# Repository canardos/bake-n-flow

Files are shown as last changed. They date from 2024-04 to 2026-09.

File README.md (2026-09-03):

# Bake-n-Flow

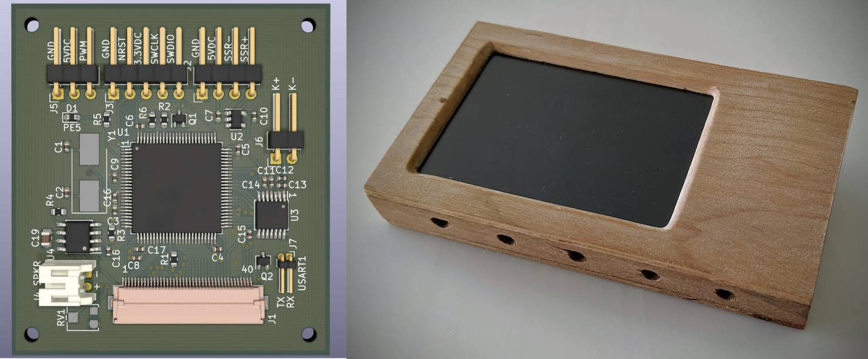
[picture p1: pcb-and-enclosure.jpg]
Reflow toaster oven controller


## Yet another (STM32F1-based) toaster reflow oven controller - PCB design and firmware

> [!Warning]
> This is personal project. It was built and works without issue for my purposes. It is made public here in case some part of it is useful to others, but **neither the hardware nor firmware have been rigorously tested**.

**Features:**

- Customizable profiles
- Reflow / baking operations
- Manual override controls
- Touch screen control

**This repo contains the firmware and PCB design.**

**See [custom electronics projects at duk.io](https://www.duk.io/blog/electronics-projects/) for full project details.**

https://github.com/canardos/bake-n-flow/assets/14832310/401d4c1e-f360-4829-90d8-4b5ea61bf341

## Build

The project uses the [PlatformIO](https://platformio.org/) dependency management/build system. If you have PlatformIO installed, executing the `run` command in the root folder *should* 🙏 be all that is required for a successful build. The `platformio.ini` file contains the required configuration and PlatformIO will download the required platform dependencies and toolchain.

**1. Clone repo and download submodules**

```shell
> git clone https://github.com/canardos/bake-n-flow.git
> cd bake-n-flow
> git submodule update --init
```

**2. Build firmware (PlatformIO must be installed)**

```shell
> pio run

Processing release (platform: ststm32; board: genericSTM32F103VD; framework: cmsis)
-----------------------------------------------------------------------------------
Verbose mode can be enabled via `-v, --verbose` option
CONFIGURATION: https://docs.platformio.org/page/boards/ststm32/genericSTM32F103VD.html
PLATFORM: ST STM32 (19.7.0) > STM32F103VD (64k RAM. 384k Flash)
HARDWARE: STM32F103VDT6 72MHz, 64KB RAM, 384KB Flash
DEBUG: Current (stlink) External (blackmagic, cmsis-dap, jlink, stlink)
PACKAGES: 
 - framework-cmsis @ 2.50501.200527 (5.5.1) 
 - framework-cmsis-stm32f1 @ 4.3.5 
 - tool-ldscripts-ststm32 @ 0.2.0 
 - toolchain-gccarmnoneeabi @ 1.120301.0 (12.3.1)
LDF: Library Dependency Finder -> https://bit.ly/configure-pio-ldf
LDF Modes: Finder ~ chain, Compatibility ~ soft
Found 4 compatible libraries
Scanning dependencies...
Dependency Graph
|-- libpekin @ 0.2.1
|-- libpekin_stm32
Building in release mode
Compiling piobuild/build/release/FrameworkCMSIS/gcc/startup_stm32f103xe.o
...
...
...
Archiving piobuild/build/release/lib7bf/libpekin_stm32.a
Indexing piobuild/build/release/lib7bf/libpekin_stm32.a
Archiving piobuild/build/release/lib72d/libpekin.a
Indexing piobuild/build/release/lib72d/libpekin.a
Linking piobuild/build/release/firmware.elf
Checking size piobuild/build/release/firmware.elf
Advanced Memory Usage is available via "PlatformIO Home > Project Inspect"
RAM:   [========= ]  95.0% (used 62248 bytes from 65536 bytes)
Flash: [=====     ]  50.5% (used 198660 bytes from 393216 bytes)
============================= [SUCCESS]
```

**3. Upload to device**

Similarly, use `pio run --target upload` to upload the firmware to the device. You'll likely need to update the upload settings in `platformio.ini` to reflect your settings, or use your own upload tool.

```shell
> pio run --target upload

Configuring upload protocol...
AVAILABLE: blackmagic, dfu, jlink, serial, stlink
CURRENT: upload_protocol = stlink
Uploading piobuild/build/release/firmware.elf
xPack OpenOCD, x86_64 Open On-Chip Debugger 0.10.0+dev-00378-ge5be992df (2020-06-26-09:27)
Licensed under GNU GPL v2
For bug reports, read
        http://openocd.org/doc/doxygen/bugs.html
debug_level: 1

hla_swd
target halted due to debug-request, current mode: Thread
xPSR: 0x01000000 pc: 0x0800108c msp: 0x20010000
** Programming Started **
** Programming Finished **
** Verify Started **
** Verified OK **
** Resetting Target **
shutdown command invoked
======================== [SUCCESS] Took 12.58 seconds =================================
```

**4. [optional] Create project files for IDE**

If you want to view/edit the project in your favorite IDE, use PlatformIO to generate the appropriate setup/workspace files and then import the project in the IDE:

```shell
> pio project init --ide [atom|clion|codeblocks|eclipse|emacs|netbeans|qtcreator|sublimetext|vim|visualstudio|vscode]
```

See the [PlatformIO documentation](https://docs.platformio.org) for further details.

### Using an alternate build system

**Platform dependencies**

If you wish to use a different build system, you will need:

| | |
|-|-|
| ST STM32 CMSIS headers | Peripheral/register definitions |
| CMSIS headers/source | CMSIS HAL functionality - SysTick_Config, NVIC_xxx etc.|
| CMSIS Cortex-M3 system source | `SystemInit()`/`SystemCoreClockUpdate()` implementation and `SystemCoreClock`|
| Startup source file | ASM file containing the startup code and vector table |
| Linker script | Tells the linker how to setup everything in flash/SRAM |

All of these are available in the [STM32 SDK](https://www.st.com/en/development-tools/stm32-software-development-tools.html) available from ST Micro.

**Compiling / linking**

`platformio.ini` lists the required compiler flags. Be sure to use `--specs=nano.specs` and `--specs=nosys.specs` when linking using your own tools, as the standard lib is be too large and is not used.

### Compiler

The project was compiled and tested with ~~`gcc-arm-none-eabi 9.2.1`~~ `gcc-arm-none-eabi 12.3.1`. It should work with any later GCC version and possibly with other compilers. The code contains some GCC flags and some C99 VLAs.

### Target requirements

| | |
|-|-|
|MCU  | STM32F103 with FSMC |
|Flash| >195kb |
|SRAM | >61kb |

It may be possible to get by with less SRAM by using a smaller drawing buffer (currently 40 lines - 38.4 kb)

## Dependencies

**CMSIS**

PlatformIO should automatically include/link the correct headers/sources from the STM32 SDK.

**LVGL**

[LVGL](https://github.com/lvgl/lvgl) v5.3 (git commit `9f216a55be65ec05c477ac55f73a6efad50f7680`) is used. It is included ~~as a Git submodule~~ in the`src/lvgl` folder.

**Libpekin**

[Libpekin](https://github.com/canardos/libpekin) is a collection of shared MCU-related code resulting from this and other projects. It's included as a Git submodule in the `lib` folder. PlatformIO will include the `lib` subfolders automatically.

## Hardware - PCB

The PCB was designed with KiCad v.5, but the files have been upgraded to v.7 and are located in `/hardware/pcb`. Gerber output for the first and only revision is located in `/hardware/pcb/plots`.

See the [KiCad documentation](https://docs.kicad.org/) for information on installing and using KiCad.

## Folder structure

```
BakeNFlow
|
+--hardware          | KiCad schematic and board design files
|
+--lib
|  |
|  +--libpekin       | Libpekin platform independent code
|  +--libpekin_stm32 | Libpekin STM32 specific code
|
+--src
|  |
|  +--audio_samples  | Audio sample data
|  +--devices        | Hardware device drivers
|  +--lvgl           | LVGL project
|  +--lvgl_driver    | Display/touch driver for LVGL
|  +--oven           | Oven hardware interface and state management
|  +--reflow         | Reflow data structures and state management
|  +--hal            | (exception handlers etc.)
|  +--ui             | UI code for LVGL
|
|--test              | No tests in use
```

## License

This software is available under the [MIT license](https://opensource.org/license/MIT).

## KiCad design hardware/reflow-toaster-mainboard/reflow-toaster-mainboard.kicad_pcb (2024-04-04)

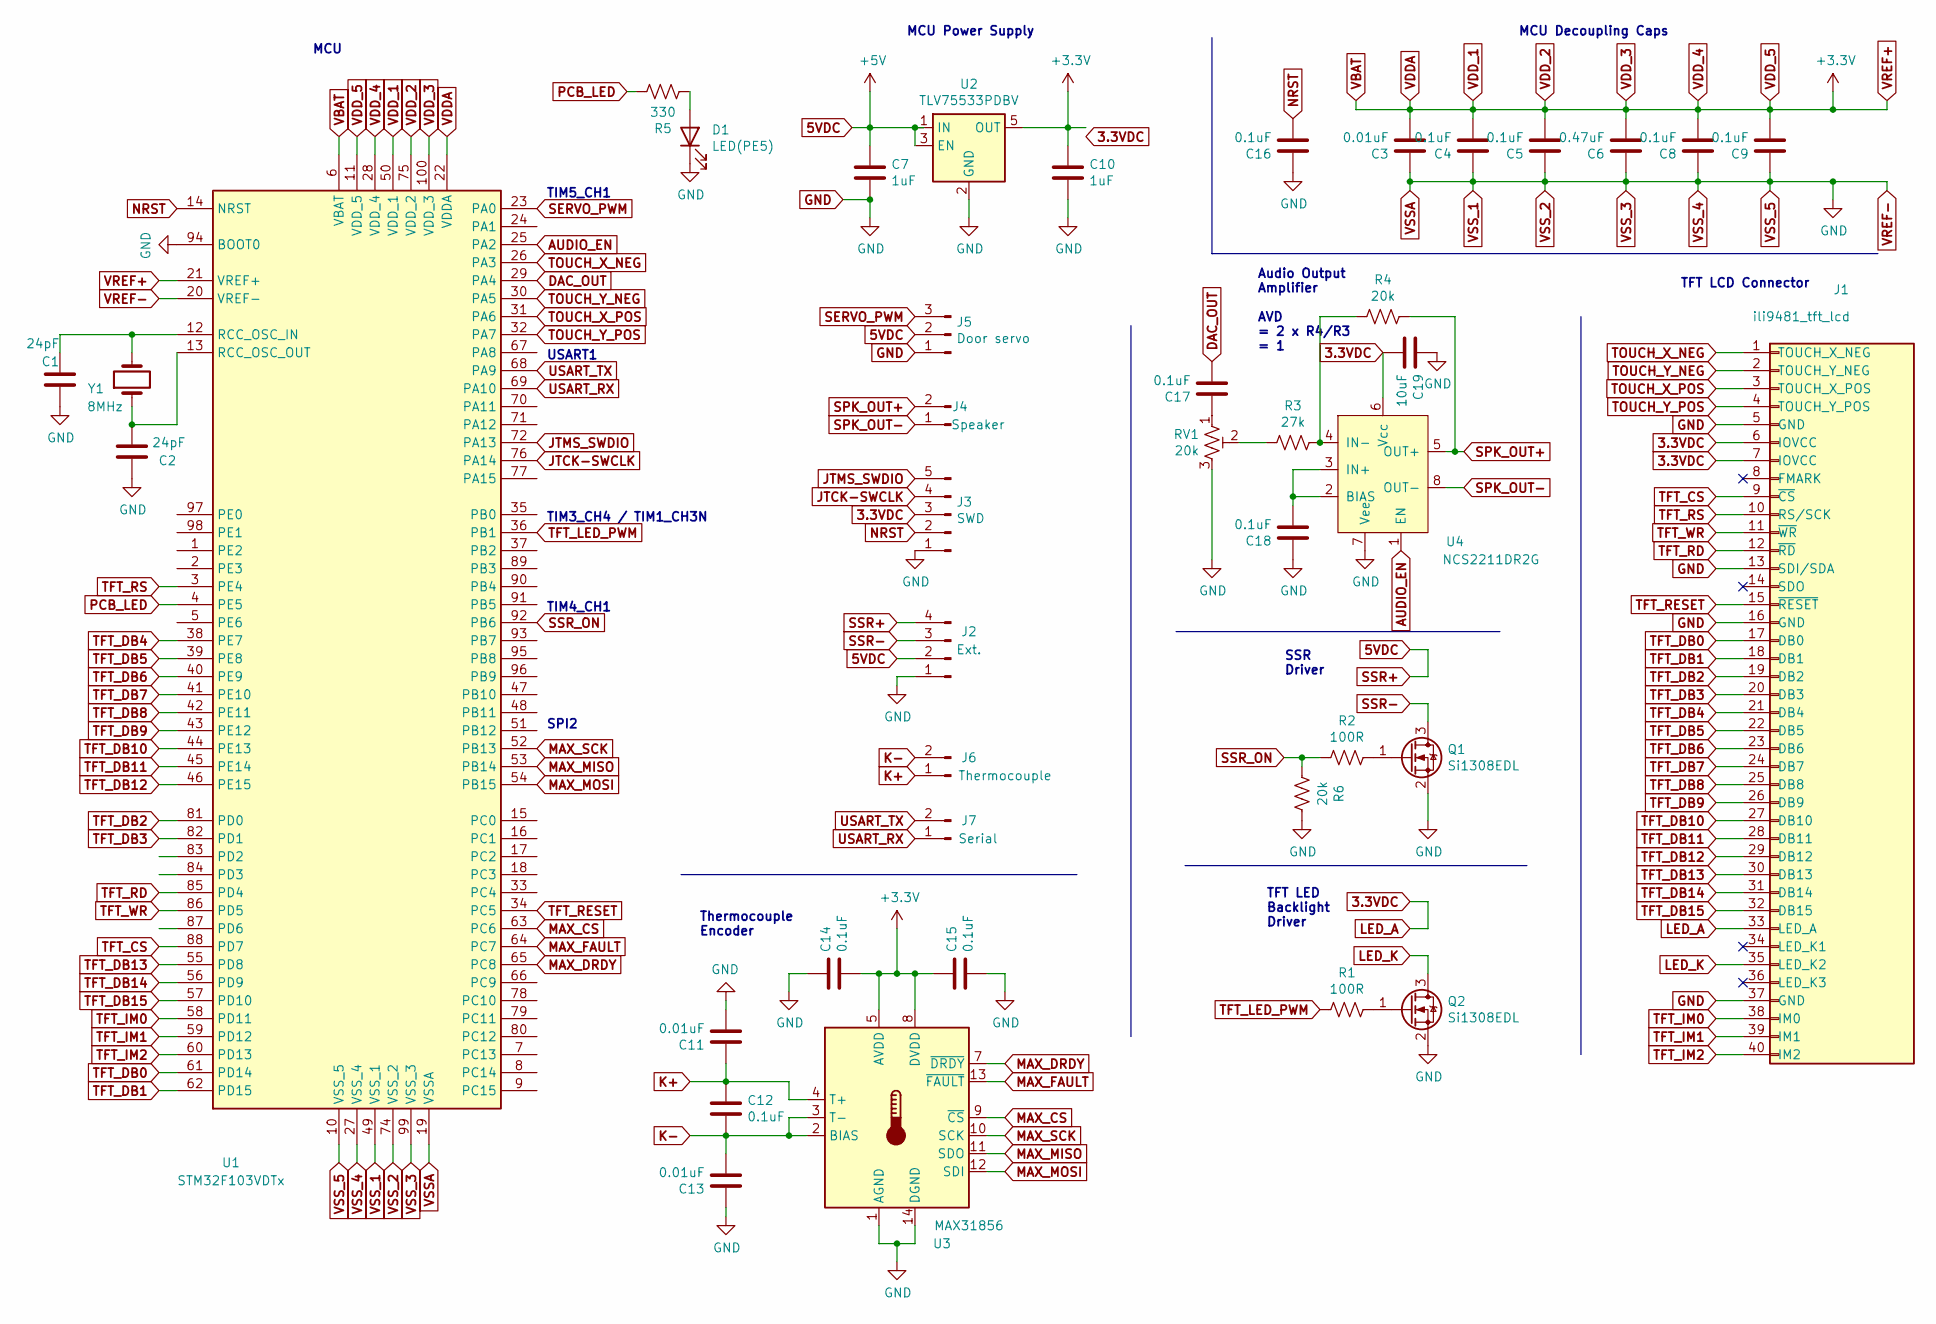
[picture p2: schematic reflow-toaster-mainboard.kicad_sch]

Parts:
C1, C2: 24pF; C_0402_1005Metric
C3, C11, C13: 0.01uF; C_0402_1005Metric
C4, C5, C8, C9, C12, C14, C15, C16, C17, C18: 0.1uF; C_0402_1005Metric
C6: 0.47uF; C_0402_1005Metric
C7, C10: 1uF; C_0402_1005Metric
C19: 10uF; C_0805_2012Metric
D1: LED(PE5); D_0603_1608Metric
J1: ili9481_tft_lcd; Hirose_FH12-40S-0.5SH_1x40-1MP_P0.50mm_Horizontal
J2: Ext.; PinHeader_1x04_P2.54mm_Horizontal
J3: SWD; PinHeader_1x05_P2.54mm_Horizontal
J4: Speaker; JST_PH_S2B-PH-K_1x02_P2.00mm_Horizontal
J5: Door servo; PinHeader_1x03_P2.54mm_Horizontal
J6: Thermocouple; PinHeader_1x02_P2.54mm_Horizontal
J7: Serial; PinHeader_1x02_P1.27mm_Horizontal
Q1, Q2: Si1308EDL; SOT-323_SC-70
R1, R2: 100R; R_0603_1608Metric
R3: 27k; R_0603_1608Metric
R4, R6: 20k; R_0603_1608Metric
R5: 330; R_0603_1608Metric
RV1: 20k; Trimmer_Potentiometer_Panasonic_EVM3W
U1: STM32F103VDTx; LQFP-100_14x14mm_P0.5mm
U2: TLV75533PDBV; SOT-23-5
U3: MAX31856; TSSOP-14_4.4x5mm_P0.65mm
U4: NCS2211DR2G; SOIC-8_3.9x4.9mm_P1.27mm
Y1: 8MHz; Crystal_SMD_7050-2Pin_7.0x5.0mm_HandSoldering

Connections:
5VDC: C7.1, J2.2, J2.4, J5.2, U2.1 (IN), U2.3 (EN)
AUDIO_EN: U1.25 (PA2), U4.1 (EN)
DAC_OUT: C17.2, U1.29 (PA4)
GND: C1.1, C2.1, C3.1, C4.1, C5.1, C6.1, C7.2, C8.1, C9.1, C10.2, C11.2, C13.1, C14.1, C15.2, C16.1, C18.1, C19.1, D1.1 (K), J1.5 (GND), J1.13 (SDI/SDA), J1.16 (GND), J1.37 (GND), J2.1, J3.1, J5.1, Q1.2 (S), Q2.2 (S), R6.1, RV1.3, U1.10 (VSS_5), U1.19 (VSSA), U1.20 (VREF-), U1.27 (VSS_4), U1.49 (VSS_1), U1.74 (VSS_2), U1.94 (BOOT0), U1.99 (VSS_3), U2.2 (GND), U3.1 (AGND), U3.14 (DGND), U4.7 (Vee)
JTCK-SWCLK: J3.4, U1.76 (PA14)
JTMS_SWDIO: J3.5, U1.72 (PA13)
K+: C11.1, C12.1, J6.1, U3.4 (T+)
K-: C12.2, C13.2, J6.2, U3.2 (BIAS), U3.3 (T-)
LED_K: J1.35 (LED_K2), Q2.3 (D)
MAX_CS: U1.63 (PC6), U3.9 (~CS)
MAX_DRDY: U1.65 (PC8), U3.7 (~DRDY)
MAX_FAULT: U1.64 (PC7), U3.13 (~FAULT)
MAX_MISO: U1.53 (PB14), U3.11 (SDO)
MAX_MOSI: U1.54 (PB15), U3.12 (SDI)
MAX_SCK: U1.52 (PB13), U3.10 (SCK)
NRST: C16.2, J3.2, U1.14 (NRST)
unnamed: C1.2, U1.12 (RCC_OSC_IN), Y1.2
unnamed: C2.2, U1.13 (RCC_OSC_OUT), Y1.1
unnamed: C17.1, RV1.1
unnamed: C18.2, U4.2 (BIAS), U4.3 (IN+)
unnamed: D1.2 (A), R5.2
unnamed: Q1.1 (G), R2.1
unnamed: Q2.1 (G), R1.1
unnamed: R3.1, R4.2, U4.4 (IN-)
unnamed: R3.2, RV1.2
PCB_LED: R5.1, U1.4 (PE5)
SERVO_PWM: J5.3, U1.23 (PA0)
SPK_OUT+: J4.2, R4.1, U4.5 (OUT+)
SPK_OUT-: J4.1, U4.8 (OUT-)
SSR-: J2.3, Q1.3 (D)
SSR_ON: R2.2, R6.2, U1.92 (PB6)
TFT_CS: J1.9 (~CS), U1.88 (PD7)
TFT_DB0: J1.17 (DB0), U1.61 (PD14)
TFT_DB1: J1.18 (DB1), U1.62 (PD15)
TFT_DB2: J1.19 (DB2), U1.81 (PD0)
TFT_DB3: J1.20 (DB3), U1.82 (PD1)
TFT_DB4: J1.21 (DB4), U1.38 (PE7)
TFT_DB5: J1.22 (DB5), U1.39 (PE8)
TFT_DB6: J1.23 (DB6), U1.40 (PE9)
TFT_DB7: J1.24 (DB7), U1.41 (PE10)
TFT_DB8: J1.25 (DB8), U1.42 (PE11)
TFT_DB9: J1.26 (DB9), U1.43 (PE12)
TFT_DB10: J1.27 (DB10), U1.44 (PE13)
TFT_DB11: J1.28 (DB11), U1.45 (PE14)
TFT_DB12: J1.29 (DB12), U1.46 (PE15)
TFT_DB13: J1.30 (DB13), U1.55 (PD8)
TFT_DB14: J1.31 (DB14), U1.56 (PD9)
TFT_DB15: J1.32 (DB15), U1.57 (PD10)
TFT_IM0: J1.38 (IM0), U1.58 (PD11)
TFT_IM1: J1.39 (IM1), U1.59 (PD12)
TFT_IM2: J1.40 (IM2), U1.60 (PD13)
TFT_LED_PWM: R1.2, U1.36 (PB1)
TFT_RD: J1.12 (~RD), U1.85 (PD4)
TFT_RESET: J1.15 (~RESET), U1.34 (PC5)
TFT_RS: J1.10 (RS/SCK), U1.3 (PE4)
TFT_WR: J1.11 (~WR), U1.86 (PD5)
TOUCH_X_NEG: J1.1 (TOUCH_X_NEG), U1.26 (PA3)
TOUCH_X_POS: J1.3 (TOUCH_X_POS), U1.31 (PA6)
TOUCH_Y_NEG: J1.2 (TOUCH_Y_NEG), U1.30 (PA5)
TOUCH_Y_POS: J1.4 (TOUCH_Y_POS), U1.32 (PA7)
USART_RX: J7.1, U1.69 (PA10)
USART_TX: J7.2, U1.68 (PA9)

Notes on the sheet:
MCU
TFT LED Backlight Driver
TIM5_CH1
Thermocouple Encoder
MCU Decoupling Caps
SSR Driver
SPI2
TFT LCD Connector
Audio Output Amplifier AVD = 2 x R4/R3 = 1
TIM4_CH1
USART1
TIM3_CH4 / TIM1_CH3N
MCU Power Supply

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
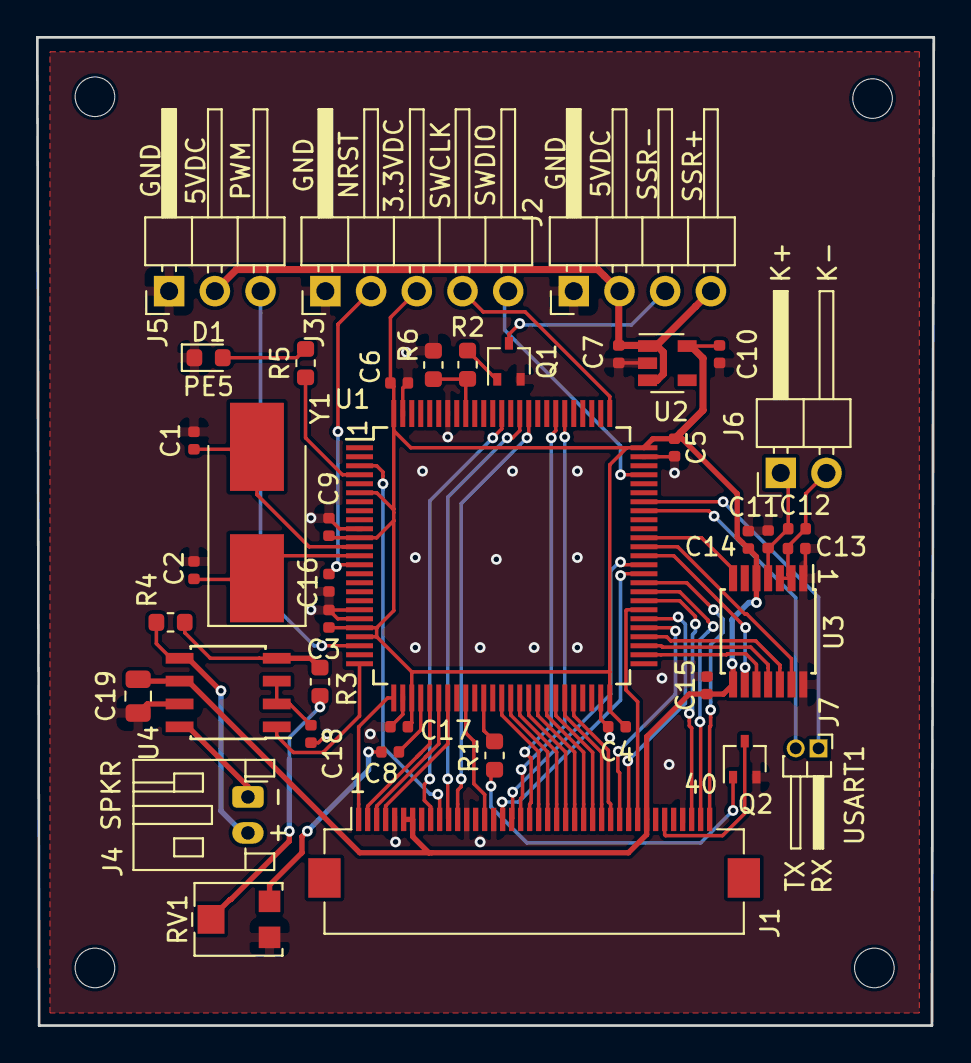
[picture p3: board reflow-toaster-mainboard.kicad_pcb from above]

Board: 2 copper layers, 49.8 x 54.9 mm, 41 parts (0 on the bottom side), 63 nets.

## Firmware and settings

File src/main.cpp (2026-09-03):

#include "app_settings.h"
#include "devices/tft.h"
#include "devices/touch.h"
#include "devices/tft_led.h"
#include "devices/speaker.h"
#include "devices/door_servo.h"
#include "devices/oven_ssr.h"
#include "devices/thermocouple.h"
#include "devices/peripherals.h"

#include "lvgl_driver/lvgl_driver.h"
#include "lvgl/lvgl.h"
#include "libpekin.h"
#include "touch/lp_touch_calibrate.h"
#include <graphics/lp_idrawing_surface.h>


using namespace libp;

/// Calibrate touch interactively and save calibration to flash.
template <typename T>
static void calibrateTouchscreen(resist_touch::Screen& touch_screen, IDrawingSurface<T>& display)
{
    AppSettings app_settings = AppSettings::get();
    if (!resist_touch::calibrateTouch(display, touch_screen)) {
        getErrHndlr().halt(ErrCode::general, "Touch calibration failed");
    }
    app_settings.settings().touch_calib_mtx = touch_screen.getCalibration();
    app_settings.writeToFlash();
}

static void initClk()
{
    using namespace libp_stm32;
    // 72 MHz
    clk::setSysClk(clk::SysClkSrc::ext_high_speed_osc, 2, clk::PllSrc::hse, 2);
    clk::setSysClk(clk::SysClkSrc::pll, 2, clk::PllSrc::hse, 9);
    clk::setHClk(clk::AhbPrescaler::div1);
    clk::setPeripheralClk(clk::ApbPrescaler::div2, clk::ApbPrescaler::div1, clk::AdcPrescaler::div6);
}

static void initDevices()
{
    initPeripherals();
    initErrHndlr();
    initSpeaker();
    initOvenSsr();
    initDoorServo();
    initThermocouple();
}

void runMainProgLoop();

int main()
{
    initClk();
    lpInitTimers();
    initDevices();

    libp::IDrawingSurface<uint16_t>& tft_display = initTftDisplay();
    resist_touch::Screen& touch_screen = initTouchscreen();

    // If screen held down on startup, set
    // brightness high and run touch calibration.

    static constexpr uint16_t touch_hold_time_ms = 2000;
    uint16_t i = 0;
    while (touch_screen.isTouched()) {
        if (i++ == touch_hold_time_ms / 10) {
            initTftLed(75);
            calibrateTouchscreen(touch_screen, tft_display);
            break;
        }
        delayMs(10);
    }

    AppSettings::Data& settings = AppSettings::get().settings();
    initTftLed(settings.brightness);

    enableSpeaker(!settings.mute);

    // Calibrate touch if we have no stored setting

    if (!settings.touch_calib_mtx.valid())
        calibrateTouchscreen(touch_screen, tft_display);
    else
        touch_screen.updateCalibration(settings.touch_calib_mtx);

    lv_init();
    initLvglHalDrivers(&touch_screen, &tft_display);

    runMainProgLoop();
}

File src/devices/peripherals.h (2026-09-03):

#ifndef MYGPIO_H_
#define MYGPIO_H_

#include <cstdint>

#include "lp_clock_stm32f1xx.h"
#include "lp_fsmc_stm32f1xx.h"
#include "lp_pins_stm32f1xx.h"

/*
 * STM32F103V[C/D/E]
 *
 * -----------------------
 * TFT LCD
 * -----------------------
 * TFT_Reset   : PC5
 *
 * TFT_RD      : PD4 (FSMC_NOE)
 * TFT_WR      : PD5 (FSMC_NWE)
 * TFT_CS      : PD7 (FSMC_NE1)
 * TFT_RS      : PE4 (FSMC_A20)
 *
 * TFT_D0      : PD14 (FSMC_D0)
 * TFT_D1      : PD15 (FSMC_D1)
 * TFT_D2      : PD0  (FSMC_D2)
 * TFT_D3      : PD1  (FSMC_D3)
 * TFT_D4      : PE7  (FSMC_D4)
 * TFT_D5      : PE8  (FSMC_D5)
 * TFT_D6      : PE9  (FSMC_D6)
 * TFT_D7      : PE10 (FSMC_D7)
 * TFT_D8      : PE11 (FSMC_D8)
 * TFT_D9      : PE12 (FSMC_D9)
 * TFT_D10     : PE13 (FSMC_D10)
 * TFT_D11     : PE14 (FSMC_D11)
 * TFT_D12     : PE15 (FSMC_D12)
 * TFT_D13     : PD8  (FSMC_D13)
 * TFT_D14     : PD9  (FSMC_D14)
 * TFT_D15     : PD10 (FSMC_D15)
 *
 * TFT_IM0     : PD11
 * TFT_IM1     : PD12
 * TFT_IM2     : PD13
 *
 * -----------------------
 * Resistive Touchscreen
 * -----------------------
 * TOUCH_X_NEG : PA3
 * TOUCH_X_POS : PA5 (ADC1/2 in5)
 * TOUCH_Y_NEG : PA6
 * TOUCH_Y_POS : PA7 (ADC1/2 in7)
 *
 * -----------------------
 * MAX31856 SPI Connection
 * -----------------------
 * MAX_CS      : PC6
 * MAX_SCK     : PB13 (SPI2)
 * MAX_MISO    : PB14 (SPI2)
 * MAX_MOSI    : PB15 (SPI2)
 * MAX_DDRY    : PC8
 * MAX_FAULT   : PC7
 *
 * -----------------------
 * Other
 * -----------------------
 * AUDIO_EN    : PA2
 * AUDIO_OUT   : PA4 (DAC)
 * SERVO_PWM   : PA0 (TIM5_CH1)
 * TFT_LED_PWM : PB1 (TIM3_CH4 / TIM1_CH3N)
 * SSR_PWM     : PB6 (TIM4_CH1)
 * PCB_LED     : PE5
 */

namespace PinNb {

inline constexpr uint8_t pcb_led = 5;
inline constexpr uint8_t audio_en = 2;
inline constexpr uint8_t audio_out = 4;

// SPI for MAX31856
inline constexpr uint8_t max_spi_cs = 6;

// TFT LCD (ex FSMC)
inline constexpr uint8_t im0 = 11;
inline constexpr uint8_t im1 = 12;
inline constexpr uint8_t im2 = 13;
inline constexpr uint8_t tft_reset = 5;
inline constexpr uint8_t tft_cs = 7;
inline constexpr uint8_t tft_rd = 4;
inline constexpr uint8_t tft_wr = 5;

// PWM
inline constexpr uint8_t door_servo_pwm = 0;
inline constexpr uint8_t ssr_pwm = 6;
inline constexpr uint8_t tft_led_pwm = 1;

}

namespace pins {

static inline libp_stm32::PinE<PinNb::pcb_led> pcb_led;
static inline libp_stm32::PinA<PinNb::audio_en> audio_en;

static inline libp_stm32::PinC<PinNb::max_spi_cs> max_spi_cs;

// TFT LCD (ex FSMC)
static inline libp_stm32::PinD<PinNb::im0> tft_im0;
static inline libp_stm32::PinD<PinNb::im1> tft_im1;
static inline libp_stm32::PinD<PinNb::im2> tft_im2;
static inline libp_stm32::PinC<PinNb::tft_reset> tft_reset;

}

namespace Details {
inline __attribute__((always_inline))
void initGpio()
{
    using namespace libp_stm32;

    clk::enable<
            clk::Apb2::iopa,
            clk::Apb2::iopb,
            clk::Apb2::iopc,
            clk::Apb2::iopd,
            clk::Apb2::iope>();

    pins::pcb_led.clear();
    pins::audio_en.clear();
    pins::max_spi_cs.clear();
    pins::tft_im0.clear();
    pins::tft_im1.clear();
    pins::tft_im2.clear();
    pins::tft_reset.clear();

    GpioA::setOutputs<OutputMode::pushpull, OutputSpeed::low,
            PinNb::audio_en >();

    GpioE::setOutputs<OutputMode::pushpull, OutputSpeed::low,
            PinNb::pcb_led >();

    GpioC::setOutputs<OutputMode::pushpull, OutputSpeed::low,
            PinNb::tft_reset,
            PinNb::max_spi_cs >();

    // SPI setup in thermocouple init

    GpioD::setOutputs<OutputMode::pushpull, OutputSpeed::low,
            PinNb::im0,
            PinNb::im1,
            PinNb::im2 >();

    // FSMC

    GpioD::setOutputs<OutputMode::alt_pushpull, OutputSpeed::high,
            8, 9, 10, 14, 15, 0, 1, PinNb::tft_rd, PinNb::tft_wr, PinNb::tft_cs >();

    GpioE::setOutputs<OutputMode::alt_pushpull, OutputSpeed::high,
            4, 7, 8, 9, 10, 11, 12, 13, 14, 15 >();

    // DAC

    GpioA::setInputs<InputMode::analog,
            PinNb::audio_out >();

    // USART

    def_pin::usart1_tx.setAsOutput(OutputMode::alt_pushpull, OutputSpeed::low);
    def_pin::usart1_rx.setAsInput(libp_stm32::InputMode::floating);
}

inline __attribute__((always_inline))
void initFsmcSram()
{
    constexpr libp_stm32::fsmc::SramNorCfg cfg = []() {
        libp_stm32::fsmc::Config config;

        config.timing.addr_setup = 5;
        config.timing.addr_hold = 2;
        config.timing.data_phase_dur = 3;

        config.addr_data_mux = false;
        config.mem_type = libp_stm32::fsmc::Config::MemType::sram;
        config.flash_access_en = false;

        return config.makeConfig();
    }();
    libp_stm32::clk::enable<libp_stm32::clk::Ahb::fsmc>();
    libp_stm32::fsmc::NorSram<1>::init(cfg);
    libp_stm32::fsmc::nadvDisconnected(); // don't use NADV output
}
} // namespace Details

inline __attribute__((always_inline))
void initPeripherals()
{
    Details::initGpio();
    Details::initFsmcSram();
}

#endif /* MYGPIO_H_ */

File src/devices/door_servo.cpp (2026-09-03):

#include <cstdint>
#include <tuple>
#include "devices/peripherals.h"

#include "lp_clock_stm32f1xx.h"
#include "lp_pins_stm32f1xx.h"
#include "lp_timer_stm32f1xx.h"

using namespace libp_stm32;

constexpr uint32_t mcu_freq = 72'000'000;

// 1->2ms pulse every 20ms = 0->180deg for standard servo
// Servo in use uses 600 -> 2050us pulse
constexpr uint32_t us_period = 20'000;
constexpr uint32_t us_for_0_deg = 1'000;
constexpr uint32_t us_for_180_deg = 2'000;
constexpr uint32_t us_for_full_arc = us_for_180_deg - us_for_0_deg;
constexpr uint32_t n_degrees = 180;

constexpr uint32_t cycles_per_deg = us_for_full_arc / (double)n_degrees * mcu_freq / 1'000'000.0;
constexpr uint32_t cycles_for_0_deg = us_for_0_deg / 1'000'000.0 * mcu_freq;
constexpr uint32_t cycles_per_period = us_period / 1'000'000.0 * mcu_freq;

static const tmr::Channel tim_channel = tmr::Channel::ch1;
static tmr::BasicTimer<TIM5_BASE> timer_;

void initDoorServo()
{
    // Timer 5, channel 1 = PA0 (no remap)
    clk::enable<clk::Apb2::iopa>();
    GpioA::setOutputs<
            OutputMode::alt_pushpull,
            OutputSpeed::low,
            PinNb::door_servo_pwm>();
    clk::enable<clk::Apb1::tim5>();

    timer_.initPwm(
            tim_channel,
            cycles_per_period,
            cycles_for_0_deg, // Or will 0 mean no movement? Preferred
            true);
}

void setDoorServo(uint16_t angle)
{
    timer_.setCompare(tim_channel, cycles_for_0_deg + angle * cycles_per_deg);
}

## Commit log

2019-03-17 Initial commit of firmware and PCB
    [reflow-toaster-mainboard-B_Cu.gbr, reflow-toaster-mainboard-B_Mask.gbr, reflow-toaster-mainboard-B_Paste.gbr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]
2024-04-04 Update PCB to KiCad v7
    [reflow-toaster-mainboard.csv, reflow-toaster-mainboard.kicad_pcb, reflow-toaster-mainboard.kicad_sch]

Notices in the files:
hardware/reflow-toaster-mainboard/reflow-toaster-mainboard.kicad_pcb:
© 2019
